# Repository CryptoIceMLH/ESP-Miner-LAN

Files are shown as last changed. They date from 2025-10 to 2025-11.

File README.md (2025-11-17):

# ESP-Miner-LAN

<a href="https://www.molonlabe.holdings/" target="_blank">molonlabe.holdings</a> for more details about my work!

If you wish to support my work you can donate with BTC:

⚡ BTC LN : cryptoice@walletofsatoshi.com

⚡ BTC Onchain: 347ePgUhyvztUWVZ4YZBmBLgTn8hxUFNeQ

Stay Tuned for updates! 
<a href="https://x.com/MolonLabeVC" target="_blank">@MolonLabeVC</a> on X 

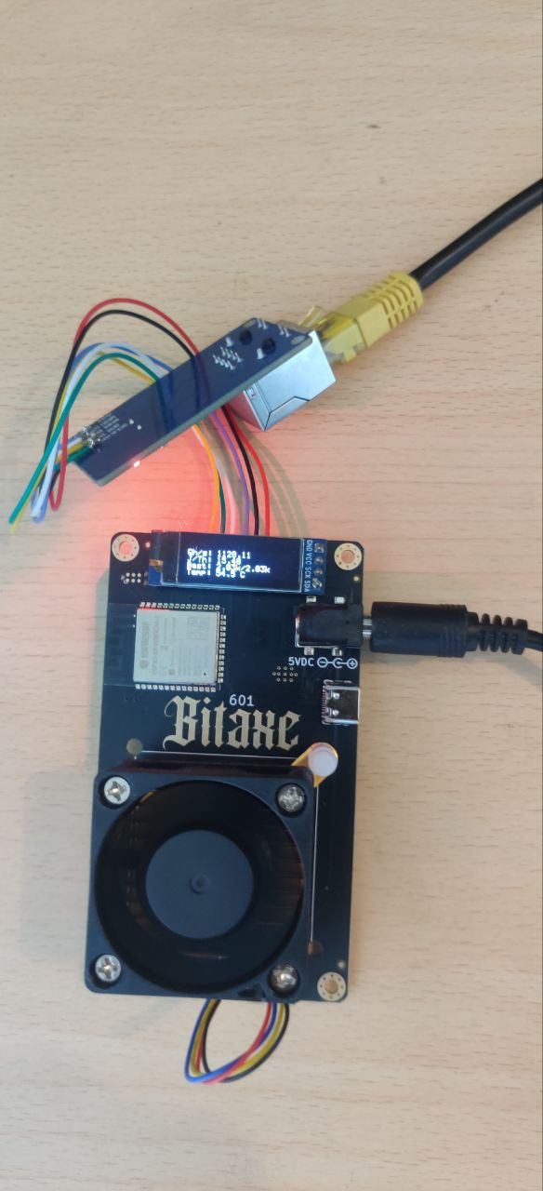
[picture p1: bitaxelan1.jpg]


# W5500 Ethernet Module Wiring Guide

This guide provides the pin connections required to add W5500 Ethernet connectivity to your BitAxe miner running the ESP-Miner-LAN firmware.
the FW is an evolution of the original bitaxe firware and is based on v2.10.1

## Table of Contents
- [Overview](#overview)
- [W5500 Module Pinout](#w5500-module-pinout)
- [ESP32-S3 to W5500 Connections](#esp32-s3-to-w5500-connections)
- [BAP UART Pinout](#bap-uart-pinout)
- [Important Notes](#important-notes)
- [Power Requirements](#power-requirements)
- [Configuration](#configuration)

## Overview

The W5500 is a hardwired TCP/IP Ethernet controller that communicates with the ESP32-S3 via SPI interface. This implementation provides a reliable wired network connection as an alternative to WiFi.

## W5500 Module Pinout

The W5500 module requires the following connections:

### W5500 Module Pin Assignment

| W5500 Pin | Signal Name | Description | Connection |
|---|---|---|---|
| MOSI | SPI MOSI | Master Out Slave In | ESP32 GPIO 40 |
| MISO | SPI MISO | Master In Slave Out | ESP32 GPIO 39 |
| SCLK | SPI Clock | SPI Clock Signal | ESP32 GPIO 41 |
| CS / SCS  | Chip Select | SPI Chip Select | ESP32 GPIO 42 |
| VCC | Power | 5v Power | 5V |
| GND | Ground | Ground | GND |

## ESP32-S3 to W5500 Connections

### Complete Wiring Table

| ESP32-S3 GPIO | Function | W5500 Pin | Wire Color Suggestion|
|---|---|---|---|
| GPIO 40 | SPI MOSI | MOSI | WHITE |
| GPIO 39 | SPI MISO | MISO | BLUE |
| GPIO 41 | SPI SCLK | SCLK | GREEN |
| GPIO 42 | SPI CS | CS/SCS | YELLOW |
| 5V | Power | VCC | Red |
| GND | Ground | GND | Black |

LOOKING at the PCB from the back and BAP port is at the bottom. working on the rear of the miner.

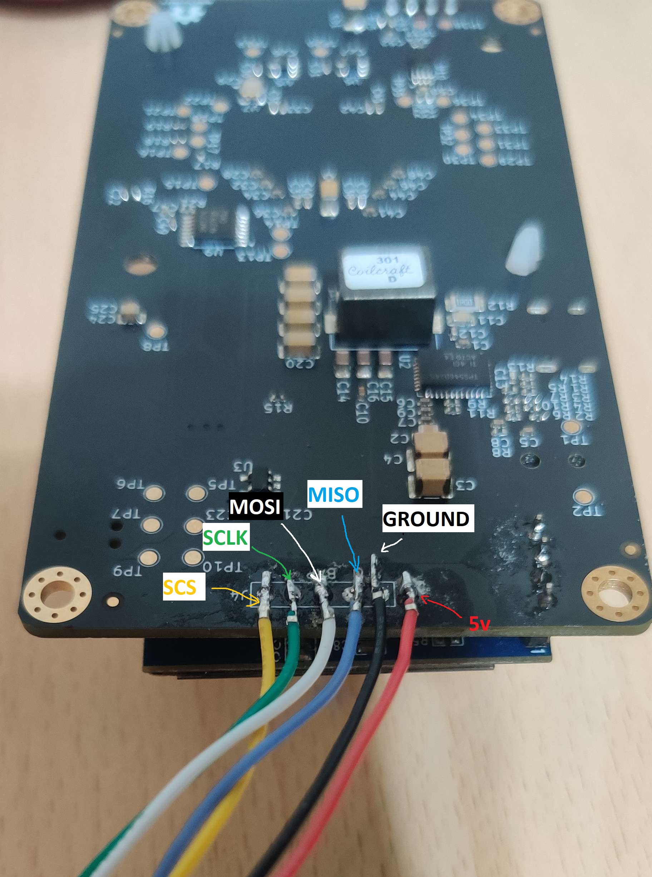
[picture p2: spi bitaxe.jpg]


### SPI Configuration

- **SPI Bus**: HSPI (SPI2)
- **SPI Clock Speed**: 20 MHz
- **SPI Mode**: Mode 0 (CPOL=0, CPHA=0)
- **Communication**: Polling mode (interrupt pin not used)

## BAP UART Pinout

The BitAxe Access Protocol (BAP) uses UART communication on the following pins:

| ESP32-S3 GPIO | Function | Description |
|---|---|---|
| GPIO 40 | BAP RX | UART Receive (from BAP device) |
| GPIO 39 | BAP TX | UART Transmit (to BAP device)  |

**⚠️ IMPORTANT PIN CONFLICT NOTE:**

GPIO 40 and GPIO 39 are shared between:
- W5500 SPI interface (MOSI and MISO)
- BAP UART interface (RX and TX)

**You cannot use both W5500 Ethernet and BAP simultaneously with the current pin configuration.**

If you need both interfaces, you must:
1. Modify the pin assignments in the configuration (see Configuration section)
2. Rebuild the firmware with updated GPIO assignments
3. Update your hardware connections accordingly

## Important Notes

### Pin Conflicts
- GPIO 40 is shared between W5500 MOSI and BAP RX
- GPIO 39 is shared between W5500 MISO and BAP TX
- Choose either Ethernet (W5500) OR BAP - not both with default pins

### Network Mode
The firmware supports two network modes:
- **WiFi Mode**: Traditional wireless connectivity
- **Ethernet Mode**: Wired connection via W5500

The system will automatically detect and use Ethernet if properly configured and connected.

### Connection Quality
- Keep SPI wires as short as possible (ideally under 15cm / 6 inches)
- Use twisted pair wiring for MOSI/MISO and SCLK/CS to reduce interference
- Ensure solid ground connection between ESP32 and W5500
- Route SPI wires away from high-power traces and switching components

## Power Requirements

### W5500 Power Specifications
- **Operating Voltage**: 5V (±5%)
- **Typical Current**: 132mA at 5V (during active Ethernet communication)
- **Peak Current**: 145mA (during PHY auto-negotiation)
- **Standby Current**: ~15mA (when idle)

### Power Calculation
**Total System Current (Ethernet Mode):**
- ESP32-S3: ~200-250mA (typical operation)
- W5500: ~132-145mA (active Ethernet)
- ASIC Mining Chip: (varies by model, 1-5A typical)
- **Total**: Add ~150mA to your existing power budget for Ethernet

## Configuration

### Enabling Ethernet in Firmware

The W5500 Ethernet interface is configured via ESP-IDF's menuconfig system:

```bash
# Open configuration menu
idf.py menuconfig
```

Navigate to: **Component config** → **Ethernet W5500 Configuration**

### Configuration Options

| Option | Default | Description |
|---|---|---|
| `W5500_SPI_MOSI` | 40 | SPI MOSI GPIO pin |
| `W5500_SPI_MISO` | 39 | SPI MISO GPIO pin |
| `W5500_SPI_SCLK` | 41 | SPI Clock GPIO pin |
| `W5500_SPI_CS` | 42 | SPI Chip Select GPIO pin |
| `W5500_INT_GPIO` | -1 | Interrupt GPIO (-1 = polling mode) |
| `W5500_SPI_CLOCK_MHZ` | 20 | SPI clock frequency in MHz |
| `ENABLE_ETHERNET` | y | Enable Ethernet support |
| `W5500_USE_DHCP` | y | Use DHCP for IP address (recommended) |

### Changing Pin Assignments

To use different GPIO pins (e.g., to avoid conflict with BAP):

1. Run `idf.py menuconfig`
2. Navigate to **Ethernet W5500 Configuration**
3. Update the GPIO pin numbers
4. Save configuration
5. Rebuild firmware: `idf.py build`
6. Flash updated firmware to device
7. Update your hardware wiring to match new pin assignments

### BAP Configuration

BAP UART pins can also be changed in menuconfig:

Navigate to: **Component config** → **BitAxe Configuration**

| Option | Default | Description |
|---|---|---|
| `GPIO_BAP_RX` | 40 | BAP UART Receive GPIO |
| `GPIO_BAP_TX` | 39 | BAP UART Transmit GPIO |
| `ENABLE_BAP` | n | Enable BAP protocol support |

## Network Configuration

### DHCP (Recommended)
By default, the W5500 uses DHCP to automatically obtain an IP address from your router. This is the easiest setup method.

### Static IP
To use a static IP address:
1. Disable `W5500_USE_DHCP` in menuconfig
2. The IP address can be configured via the AxeOS web interface
3. Alternatively, modify the Ethernet initialization code in `components/ethernet_w5500/ethernet_w5500.c`

## References 
- **W5500 Datasheet**: https://www.wiznet.io/product-item/w5500/
- **ESP-IDF Ethernet Documentation**: https://docs.espressif.com/projects/esp-idf/en/latest/esp32s3/api-reference/network/esp_eth.html
- **BitAxe Project**: https://github.com/bitaxeorg/bitaxe
- **ORIGINAL ESP-Miner Firmware**: https://github.com/bitaxeorg/ESP-Miner

##
**⚠️ WARNING**: Incorrect wiring can damage your ESP32 and/or W5500 module. Double-check all connections before applying power. When in doubt, consult the data sheets or ask for help in the community Discord. The Author takes NO responsibility.  Use this project content at your OWN RISK!

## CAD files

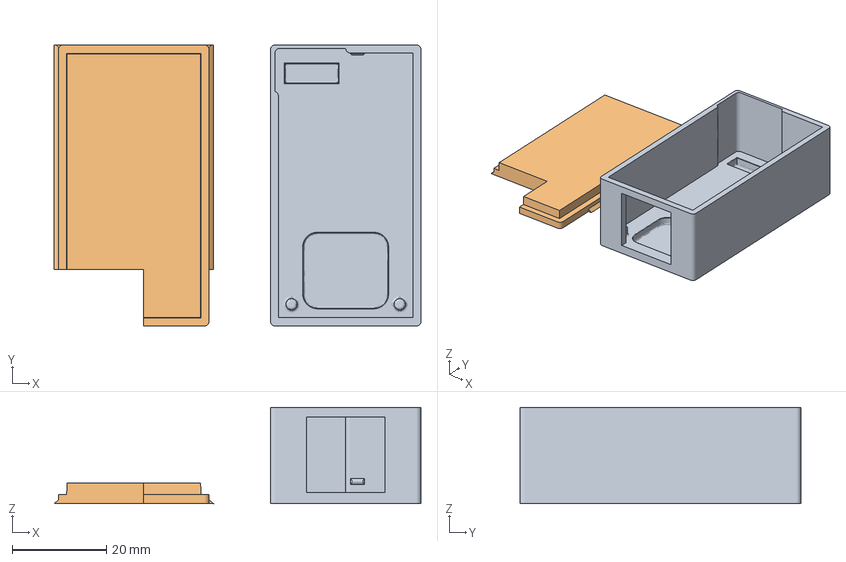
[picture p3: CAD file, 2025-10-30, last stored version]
enclosures/W5500 Case.3mf
77.7 x 59.5 x 20.4 mm
W5500 Case
W5500 Case (Lid).stl

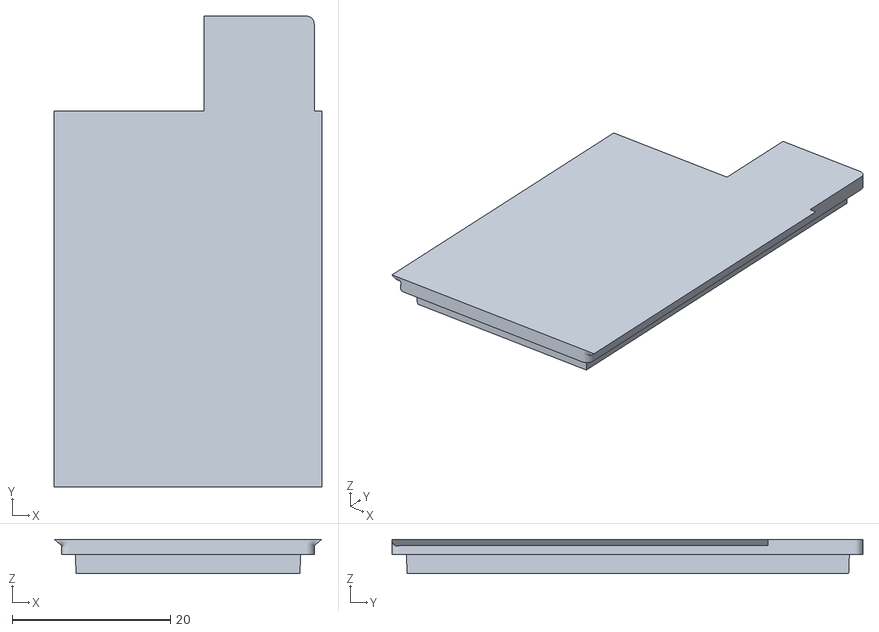
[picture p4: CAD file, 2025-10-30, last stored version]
enclosures/W5500 Case (Lid).stl
33.8 x 59.5 x 4.33

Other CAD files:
enclosures/W5500 Case.stl

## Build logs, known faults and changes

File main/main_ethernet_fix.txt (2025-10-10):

    if (use_ethernet) {
        ESP_LOGI(TAG, "Network mode: Ethernet - Initializing...");
        // Try to init Ethernet
        ethernet_init(&GLOBAL_STATE);
        ESP_LOGI(TAG, "DEBUG: After ethernet_init, eth_available = %d", GLOBAL_STATE.ETHERNET_MODULE.eth_available);

        // Wait for Ethernet to get IP and update is_connected flag
        if (GLOBAL_STATE.ETHERNET_MODULE.eth_available) {
            ESP_LOGI(TAG, "Waiting for Ethernet IP address...");
            int retry_count = 0;
            while (retry_count < 100) {  // Wait up to 10 seconds
                ethernet_update_status(&GLOBAL_STATE);
                if (GLOBAL_STATE.SYSTEM_MODULE.is_connected) {
                    ESP_LOGI(TAG, "Ethernet connected with IP: %s", GLOBAL_STATE.ETHERNET_MODULE.eth_ip_addr_str);
                    break;
                }
                vTaskDelay(100 / portTICK_PERIOD_MS);
                retry_count++;
            }
            if (!GLOBAL_STATE.SYSTEM_MODULE.is_connected) {
                ESP_LOGW(TAG, "Ethernet timeout, falling back to WiFi");
                wifi_init(&GLOBAL_STATE);
            }
        } else {
            ESP_LOGW(TAG, "Ethernet unavailable, initializing WiFi fallback");
            wifi_init(&GLOBAL_STATE);
        }
    } else {

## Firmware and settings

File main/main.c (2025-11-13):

#include "esp_event.h"
#include "esp_log.h"
#include "esp_psram.h"
#include "nvs_flash.h"

#include "asic_result_task.h"
#include "asic_task.h"
#include "create_jobs_task.h"
#include "statistics_task.h"
#include "system.h"
#include "http_server.h"
#include "serial.h"
#include "stratum_task.h"
#include "i2c_bitaxe.h"
#include "adc.h"
#include "nvs_device.h"
#include "nvs_config.h"
#include "self_test.h"
#include "asic.h"
#include "bap/bap.h"
#include "device_config.h"
#include "connect.h"
#include "asic_reset.h"

static GlobalState GLOBAL_STATE;

static const char * TAG = "bitaxe";

void app_main(void)
{
    ESP_LOGI(TAG, "Welcome to the bitaxe - FOSS || GTFO!");

    if (!esp_psram_is_initialized()) {
        ESP_LOGE(TAG, "No PSRAM available on ESP32 device!");
        GLOBAL_STATE.psram_is_available = false;
    } else {
        GLOBAL_STATE.psram_is_available = true;
    }

    // Init I2C
    ESP_ERROR_CHECK(i2c_bitaxe_init());
    ESP_LOGI(TAG, "I2C initialized successfully");

    //wait for I2C to init
    vTaskDelay(100 / portTICK_PERIOD_MS);

    //Init ADC
    ADC_init();

    //initialize the ESP32 NVS
    if (NVSDevice_init() != ESP_OK){
        ESP_LOGE(TAG, "Failed to init NVS");
        return;
    }

    if (device_config_init(&GLOBAL_STATE) != ESP_OK) {
        ESP_LOGE(TAG, "Failed to init device config");
        return;
    }

    if (self_test(&GLOBAL_STATE)) return;

    SYSTEM_init_system(&GLOBAL_STATE);
    statistics_init(&GLOBAL_STATE);

    // Initialize network infrastructure ONCE before any interface init
    network_infrastructure_init();

    // Read network mode to determine which interface to initialize
    char *network_mode_str = nvs_config_get_string(NVS_CONFIG_NETWORK_MODE, "wifi");
    bool use_ethernet = (strcmp(network_mode_str, "ethernet") == 0);
    free(network_mode_str);

    if (use_ethernet) {
        ESP_LOGI(TAG, "Network mode: Ethernet - Initializing...");
        // Try to init Ethernet
        ethernet_init(&GLOBAL_STATE);
        ESP_LOGI(TAG, "DEBUG: After ethernet_init, eth_available = %d", GLOBAL_STATE.ETHERNET_MODULE.eth_available);

        // Wait for Ethernet to get IP and update is_connected flag
        if (GLOBAL_STATE.ETHERNET_MODULE.eth_available) {
            ESP_LOGI(TAG, "Waiting for Ethernet IP address...");
            int retry_count = 0;
            while (retry_count < 100) {  // Wait up to 10 seconds
                ethernet_update_status(&GLOBAL_STATE);
                if (GLOBAL_STATE.SYSTEM_MODULE.is_connected) {
                    ESP_LOGI(TAG, "Ethernet connected with IP: %s", GLOBAL_STATE.ETHERNET_MODULE.eth_ip_addr_str);
                    break;
                }
                vTaskDelay(100 / portTICK_PERIOD_MS);
                retry_count++;
            }
            if (!GLOBAL_STATE.SYSTEM_MODULE.is_connected) {
                ESP_LOGW(TAG, "Ethernet timeout, falling back to WiFi");
                wifi_init(&GLOBAL_STATE);
            }
        } else {
            ESP_LOGW(TAG, "Ethernet unavailable, initializing WiFi fallback");
            wifi_init(&GLOBAL_STATE);
        }
    } else {        ESP_LOGI(TAG, "Network mode: WiFi");
        // init AP and connect to wifi
        wifi_init(&GLOBAL_STATE);
        // init Ethernet detection (but not full init)
        ethernet_init(&GLOBAL_STATE);
        ESP_LOGI(TAG, "DEBUG: After ethernet_init, eth_available = %d", GLOBAL_STATE.ETHERNET_MODULE.eth_available);
    }

    SYSTEM_init_peripherals(&GLOBAL_STATE);

    xTaskCreate(POWER_MANAGEMENT_task, "power management", 8192, (void *) &GLOBAL_STATE, 10, NULL);

    //start the API for AxeOS
    start_rest_server((void *) &GLOBAL_STATE);

#ifdef CONFIG_ENABLE_BAP
    // Initialize BAP interface
    esp_err_t bap_ret = BAP_init(&GLOBAL_STATE);
    if (bap_ret != ESP_OK) {
        ESP_LOGE(TAG, "Failed to initialize BAP interface: %d", bap_ret);
        // Continue anyway, as BAP is not critical for core functionality
    } else {
        ESP_LOGI(TAG, "BAP interface initialized successfully");
    }
#endif

    while (!GLOBAL_STATE.SYSTEM_MODULE.is_connected) {
        vTaskDelay(100 / portTICK_PERIOD_MS);
    }

    queue_init(&GLOBAL_STATE.stratum_queue);
    queue_init(&GLOBAL_STATE.ASIC_jobs_queue);

    if (asic_reset() != ESP_OK) {
        GLOBAL_STATE.SYSTEM_MODULE.asic_status = "ASIC reset failed";
        ESP_LOGE(TAG, "ASIC reset failed!");
        return;
    }

    SERIAL_init();

    if (ASIC_init(&GLOBAL_STATE) == 0) {
        GLOBAL_STATE.SYSTEM_MODULE.asic_status = "Chip count 0";
        ESP_LOGE(TAG, "Chip count 0");
        return;
    }

    SERIAL_set_baud(ASIC_set_max_baud(&GLOBAL_STATE));
    SERIAL_clear_buffer();

    GLOBAL_STATE.ASIC_initalized = true;

    xTaskCreate(stratum_task, "stratum admin", 8192, (void *) &GLOBAL_STATE, 5, NULL);
    xTaskCreate(create_jobs_task, "stratum miner", 8192, (void *) &GLOBAL_STATE, 10, NULL);
    xTaskCreate(ASIC_task, "asic", 8192, (void *) &GLOBAL_STATE, 10, NULL);
    xTaskCreate(ASIC_result_task, "asic result", 8192, (void *) &GLOBAL_STATE, 15, NULL);
    xTaskCreate(statistics_task, "statistics", 8192, (void *) &GLOBAL_STATE, 3, NULL);
}

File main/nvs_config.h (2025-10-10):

#ifndef MAIN_NVS_CONFIG_H
#define MAIN_NVS_CONFIG_H

#include <stdint.h>

// Max length 15

#define NVS_CONFIG_WIFI_SSID "wifissid"
#define NVS_CONFIG_WIFI_PASS "wifipass"
#define NVS_CONFIG_HOSTNAME "hostname"
#define NVS_CONFIG_STRATUM_URL "stratumurl"
#define NVS_CONFIG_STRATUM_PORT "stratumport"
#define NVS_CONFIG_FALLBACK_STRATUM_URL "fbstratumurl"
#define NVS_CONFIG_FALLBACK_STRATUM_PORT "fbstratumport"
#define NVS_CONFIG_STRATUM_USER "stratumuser"
#define NVS_CONFIG_STRATUM_EXTRANONCE_SUBSCRIBE "stratumxnsub"
#define NVS_CONFIG_STRATUM_DIFFICULTY "stratumdiff"
#define NVS_CONFIG_STRATUM_PASS "stratumpass"
#define NVS_CONFIG_FALLBACK_STRATUM_USER "fbstratumuser"
#define NVS_CONFIG_FALLBACK_STRATUM_EXTRANONCE_SUBSCRIBE "stratumfbxnsub"
#define NVS_CONFIG_FALLBACK_STRATUM_DIFFICULTY "fbstratumdiff"
#define NVS_CONFIG_FALLBACK_STRATUM_PASS "fbstratumpass"
#define NVS_CONFIG_ASIC_FREQUENCY "asicfrequency"
#define NVS_CONFIG_ASIC_FREQUENCY_FLOAT "asicfrequency_f"
#define NVS_CONFIG_ASIC_VOLTAGE "asicvoltage"
#define NVS_CONFIG_ASIC_MODEL "asicmodel"
#define NVS_CONFIG_DEVICE_MODEL "devicemodel"
#define NVS_CONFIG_BOARD_VERSION "boardversion"
#define NVS_CONFIG_DISPLAY "display"
#define NVS_CONFIG_ROTATION "rotation"
#define NVS_CONFIG_INVERT_SCREEN "invertscreen"
#define NVS_CONFIG_DISPLAY_TIMEOUT "displayTimeout"
#define NVS_CONFIG_AUTO_FAN_SPEED "autofanspeed"
#define NVS_CONFIG_FAN_SPEED "fanspeed"
#define NVS_CONFIG_MIN_FAN_SPEED "minfanspeed"
#define NVS_CONFIG_TEMP_TARGET "temptarget"
#define NVS_CONFIG_BEST_DIFF "bestdiff"
#define NVS_CONFIG_SELF_TEST "selftest"
#define NVS_CONFIG_OVERHEAT_MODE "overheat_mode"
#define NVS_CONFIG_OVERCLOCK_ENABLED "oc_enabled"
#define NVS_CONFIG_SWARM "swarmconfig"
#define NVS_CONFIG_STATISTICS_FREQUENCY "statsFrequency"

// Theme configuration
#define NVS_CONFIG_THEME_SCHEME "themescheme"
#define NVS_CONFIG_THEME_COLORS "themecolors"

// Device config overrides
#define NVS_CONFIG_PLUG_SENSE "plug_sense"
#define NVS_CONFIG_ASIC_ENABLE "asic_enable"
#define NVS_CONFIG_EMC2101 "EMC2101"
#define NVS_CONFIG_EMC2103 "EMC2103"
#define NVS_CONFIG_EMC_INTERNAL_TEMP "emc_int_temp"
#define NVS_CONFIG_EMC_IDEALITY_FACTOR "emc_ideality_f"
#define NVS_CONFIG_EMC_BETA_COMPENSATION "emc_beta_comp"
#define NVS_CONFIG_EMC_TEMP_OFFSET "emc_temp_offset"
#define NVS_CONFIG_DS4432U "DS4432U"
#define NVS_CONFIG_INA260 "INA260"
#define NVS_CONFIG_TPS546 "TPS546"
#define NVS_CONFIG_POWER_CONSUMPTION_TARGET "power_cons_tgt"

// Ethernet configuration
#define NVS_CONFIG_NETWORK_MODE "network_mode"
#define NVS_CONFIG_ETH_STATIC_IP "eth_static_ip"
#define NVS_CONFIG_ETH_GATEWAY "eth_gateway"
#define NVS_CONFIG_ETH_SUBNET "eth_subnet"
#define NVS_CONFIG_ETH_DNS "eth_dns"
#define NVS_CONFIG_ETH_USE_DHCP "eth_use_dhcp"

char * nvs_config_get_string(const char * key, const char * default_value);
void nvs_config_set_string(const char * key, const char * default_value);
uint16_t nvs_config_get_u16(const char * key, const uint16_t default_value);
void nvs_config_set_u16(const char * key, const uint16_t value);
int32_t nvs_config_get_i32(const char * key, const int32_t default_value);
void nvs_config_set_i32(const char * key, const int32_t value);
uint64_t nvs_config_get_u64(const char * key, const uint64_t default_value);
void nvs_config_set_u64(const char * key, const uint64_t value);
float nvs_config_get_float(const char *key, float default_value);
void nvs_config_set_float(const char *key, float value);
void nvs_config_commit(void);

#endif // MAIN_NVS_CONFIG_H

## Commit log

2025-10-10 full upload to FOS the LAN mod
    full upload
    [partitions.csv]
2025-10-29 Add README for 3D printable enclosures
2025-11-13 all g t g
    [W5500 Case (Lid).stl, W5500 Case.3mf, W5500 Case.stl]
